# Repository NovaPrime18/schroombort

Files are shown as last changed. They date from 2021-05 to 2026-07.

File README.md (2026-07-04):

<div align="center">

# Schroombort

**An over-engineered, battery-powered mechanical soundboard.**

Press a button, hear a dumb sound. Then find out it's also a macro-pad. And a calculator.



[]()
[]()

[**▶ Watch the cinematic trailer**](https://www.youtube.com/watch?v=MM4cooladaY)

</div>

---

## Renders

<div align="center">
<table>
<tr>
<td align="center" width="50%">
Schroombort 3D render<br>
</td>
<td align="center" width="50%">
Schroombort real-life photo<br>
</td>
</tr>
</table>
</div>

---

## What is it..?

Schroombort is a battery-powered soundboard built around **36 mechanical (Cherry MX‑style) switches**, a **Vacuum Fluorescent Display**, and stereo speakers — designed to do way more than it needs to. It runs in one of three configurations, switchable depending on how you're using it.

## ⚙️ Configurations

| Mode | Description |
|---|---|
| **Soundboard** | Press a button, and a sound is played straight from the SD card. |
| **Macro-pad** | Plug it into your computer over USB‑C and assign each of the 36 buttons to a custom macro. |
| **Calculator** | Flip it into a fully functional basic calculator. |

## Specs

| Category | Detail |
|---|---|
| **Charging** | Any 5V charger, up to 2A |
| **Power management** | Fully dynamic power-path management — runs entirely on USB, entirely on battery, or a mix of both, seamlessly |
| **Inputs** | 36 configurable mechanical buttons |
| **Audio** | Stereo speakers |
| **Microcontroller** | ATxmega256A3U |
| **Display** | Vacuum Fluorescent Display (VFD) |
| **Connectivity** | USB-C |

## Repository structure

```
schroombort/
├── HardwareSchroombortFirmware/   # Firmware source code
├── PCB Files/                     # KiCad hardware design files
├── Pictures/                      # Renders & photos of the build
└── LICENSE                        # CERN-OHL-S v2.0
```

## Cinematic trailer

Because a README alone can't do it justice:

**[▶ https://www.youtube.com/watch?v=MM4cooladaY](https://www.youtube.com/watch?v=MM4cooladaY)**

## License

This project is open hardware, licensed under the **[CERN Open Hardware Licence Version 2 - Strongly Reciprocal (CERN-OHL-S v2.0)](https://ohwr.org/cern_ohl_s_v2.txt)**.

Any modified versions of the hardware distributed must remain under the same license, and source (including any modifications) must be made available.

---

<div align="center">
<sub>Built with too much love for a device whose main job is playing dumb sounds.</sub>
</div>

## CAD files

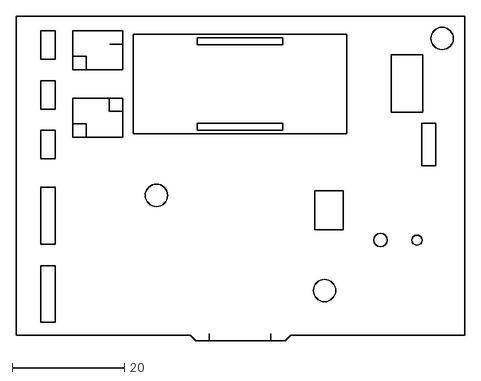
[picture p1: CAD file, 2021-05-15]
PCB Files/buttonbox2-Eco1.User.dxf
80.0 x 58.0

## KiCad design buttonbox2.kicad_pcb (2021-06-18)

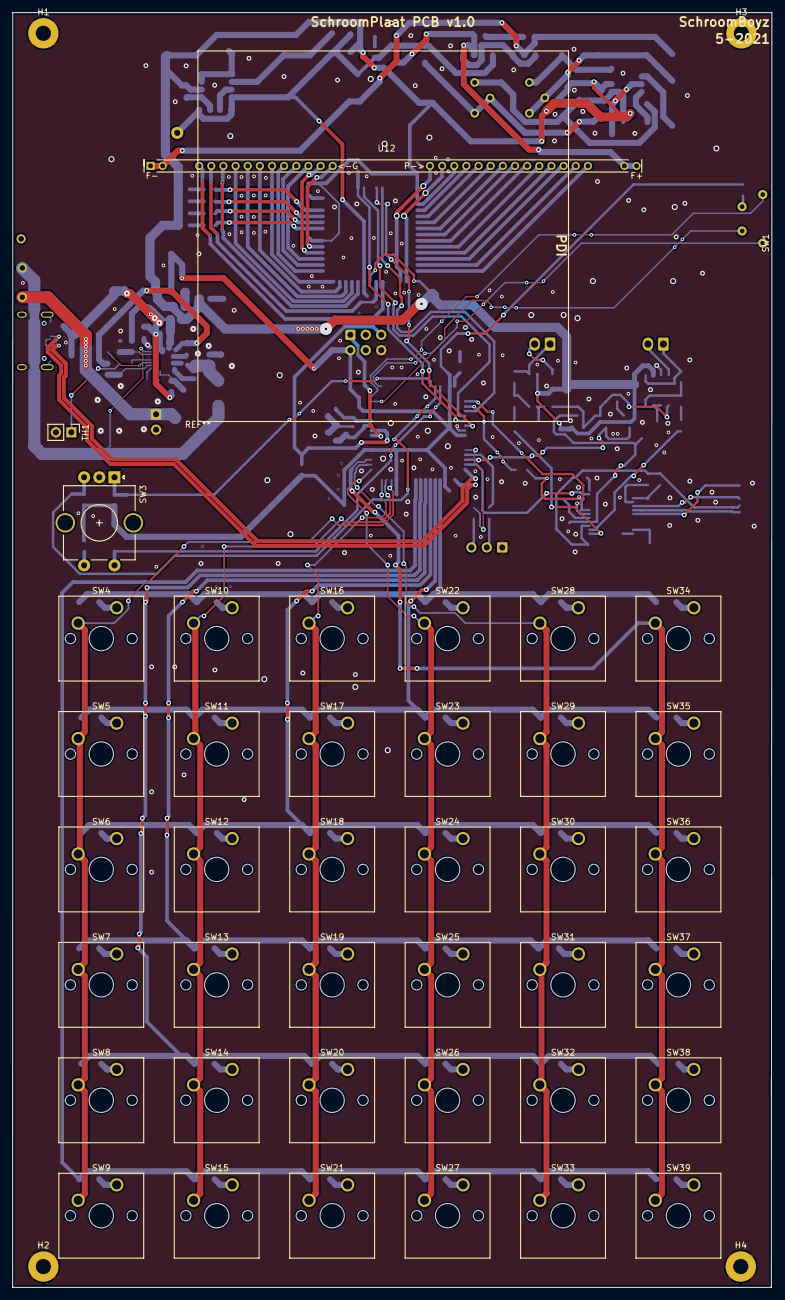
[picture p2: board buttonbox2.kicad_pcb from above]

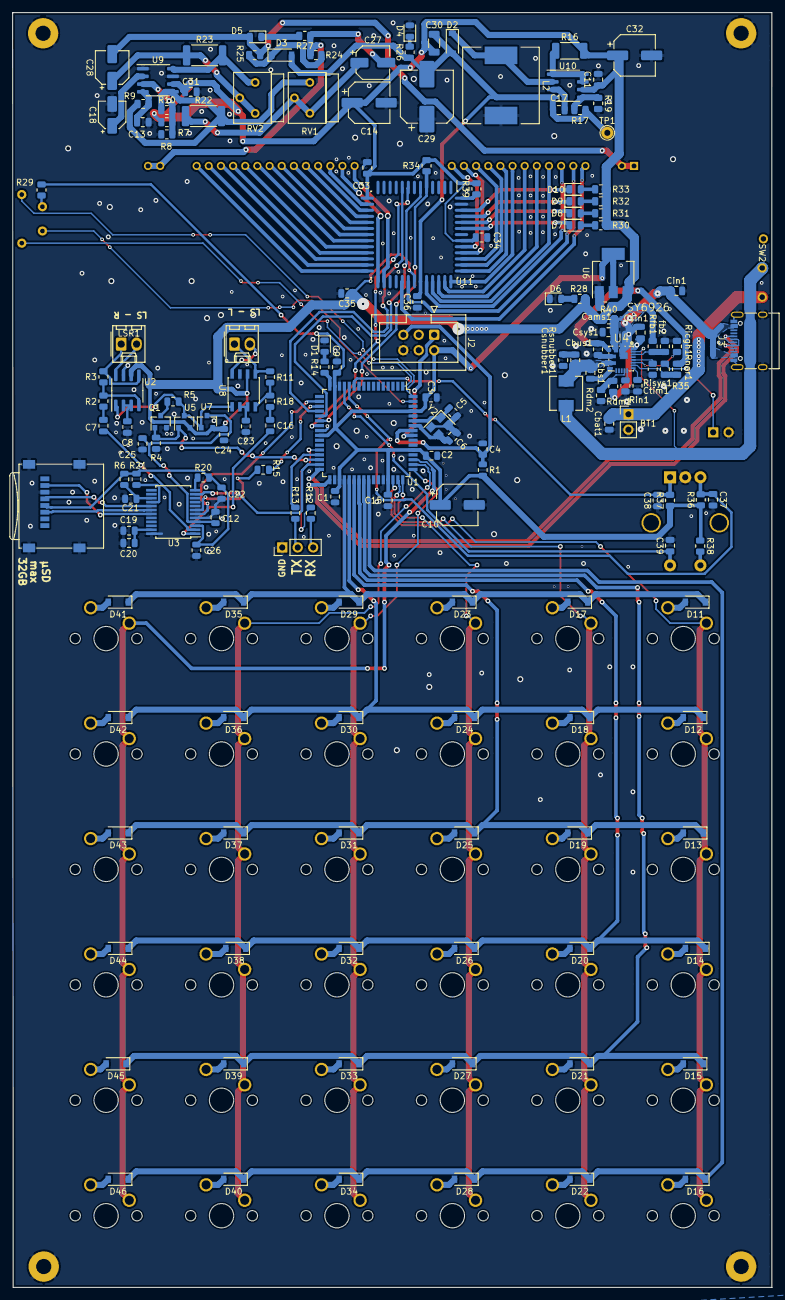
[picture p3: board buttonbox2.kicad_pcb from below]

Board: 2 copper layers, 125.0 x 209.8 mm, 213 parts (169 on the bottom side), 172 nets.

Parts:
BT1: Battery; PinHeader_1x02_P2.54mm_Vertical
C1, C2, C3, C4, C9, C11, C13, C19, C24, C25, C26, C31, C33, C34, C35, C36, C37, C38, C39: 100n; C_0805_2012Metric
C5, C6: 10p; C_0805_2012Metric
C7, C16, C20, C22: 10u; C_0805_2012Metric
C8, C12, C21, C23: 1u; C_0805_2012Metric
C10, C14, C32: 100u; CP_Elec_6.3x5.4
C15: 4.7u; C_0805_2012Metric
C17: 1n; C_0805_2012Metric
C18: 1u; CP_Elec_4x5.4
C27, C28: 10u-50V; CP_Elec_5x5.4
C29: 100u-50V; CP_Elec_8x10.5
C30: 10u 50V; C_1206_3216Metric
Cams1: C; C_0805_2012Metric
Cbat1: 20uF; C_0805_2012Metric
Cbs1: 1nF; C_0805_2012Metric
Cbus1: 20uF; C_0805_2012Metric
Cin1: 20uF; C_0805_2012Metric
Csin1: 100nF; C_0805_2012Metric
Csnubber1: DNP; C_0805_2012Metric
Csys1: 20uF; C_0805_2012Metric
Ctim1: 100nF; C_0805_2012Metric
D1, D4, D5, D6, D7, D8, D9, D10: LED; LED_0805_2012Metric
D2: 1N5819; D_SOD-123
D3: 3.6V; D_SOD-123
D11, D12, D13, D14, D15, D16, D17, D18, D19, D20, D21, D22, D23, D24, D25, D26, D27, D28, D29, D30, D31, D32, D33, D34, D35, D36, D37, D38, D39, D40, D41, D42, D43, D44, D45, D46: D_Small; D_SOD-123
H1, H2, H3, H4: MountingHole_Pad; MountingHole_2.5mm_Pad
J2: AVR-PDI-6; IDC-Header_2x03_P2.54mm_Vertical
J3: USB_C_Receptacle_USB2.0; USB_C_Receptacle_XKB_U262-16XN-4BVC11
J4: Conn_01x03_Male; PinHeader_1x03_P2.54mm_Vertical
J6: Micro_SD_Card; microSD_HC_Wuerth_693072010801
L1: 2.2uH; L_Sunlord_MWSA0518_5.4x5.2mm
L2: 470u; L_12x12mm_H8mm
LSL1: Speaker; Molex_KK-254_AE-6410-02A_1x02_P2.54mm_Vertical
LSR1: Speaker; Molex_KK-254_AE-6410-02A_1x02_P2.54mm_Vertical
Q1: 2N7002; SOT-23
R1, R2, R4, R5, R7, R8, R10, R14, R18, R27, R28, R29, R34, R36, R37, R38: 10K; R_0805_2012Metric
R3, R11: TBD; R_0805_2012Metric
R6, R20, R21: 22K; R_0805_2012Metric
R9: 2.2K; R_0805_2012Metric
R12, R13: 100R; R_0805_2012Metric
R15: 1K; R_0805_2012Metric
R16: 0.3 2W; R_2010_5025Metric
R17: 20K; R_0805_2012Metric
R19: 390K; R_0805_2012Metric
R22, R23: 150 2W; R_2512_6332Metric
R24, R25: 100; R_0805_2012Metric
R26: 100K; R_0805_2012Metric
R30, R31, R32, R33: 330; R_0805_2012Metric
R35: 4.4K; R_0805_2012Metric
R39: 56K; R_0805_2012Metric
R40: DNP; R_0805_2012Metric
RV1, RV2: 500; Potentiometer_Bourns_3339S_Horizontal
Rdm1: 33K; R_0805_2012Metric
Rdm2: 9.1K; R_0805_2012Metric
Rfb1: 33K; R_0805_2012Metric
Ricgh1: 10.666K; R_0805_2012Metric
Rin1: 1K; R_0805_2012Metric
Risys1: 36K; R_0805_2012Metric
Rnor1: 22K; R_0805_2012Metric
Rsnubber1: DNP; R_0805_2012Metric
SW1: SW_SP3T; schakelaar
SW2: SW_SPDT; SWINTCHFORBATTERY
SW3: Rotary_Encoder_Switch; RotaryEncoder_Alps_EC11E-Switch_Vertical_H20mm_CircularMoun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
SW4, SW5, SW6, SW7, SW8, SW9, SW10, SW11, SW12, SW13, SW14, SW15, SW16, SW17, SW18, SW19, SW20, SW21, SW22, SW23, SW24, SW25, SW26, SW27, SW28, SW29, SW30, SW31, SW32, SW33, SW34, SW35, SW36, SW37, SW38, SW39: SW_Push; SW_Cherry_MX_1.00u_PCB_BETTER
TH1: Thermistor_NTC; PinHeader_1x02_P2.54mm_Vertical
TP1: TestPoint; TestPoint_THTPad_D2.0mm_Drill1.0mm
U1: ATxmega256A3-AU; TQFP-64_14x14mm_P0.8mm
U2, U8, U9: LM4871; SOIC-8_3.9x4.9mm_P1.27mm
U3: YX5200-24SS; SSOP-24_5.3x8.2mm_P0.65mm
U4: SY6926; QFN-20_L4.0-W4.0-P0.45-BL
U5, U7: DMG3415; SOT-23
U6: AMS1117-3.3; SOT-223-3_TabPin2
U10: MC34063AD; SOIC-8_3.9x4.9mm_P1.27mm
U11: PT6311; LQFP-52_14x14_Pitch1mm
U12: VFD_HNV-12SS62; VFD_12SGMT
Y2: Crystal_GND24; Crystal_SMD_3225-4Pin_3.2x2.5mm
fb2: 10.3K; R_0805_2012Metric

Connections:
+3V3: C1.1, C2.1, C3.1, C9.1, C10.1, C15.1, J2.2, R1.1, R29.1, R36.1, R37.1, R38.1, U1.15, U1.25, U1.35, U1.45, U1.53, U1.61, U6.2
+5P: C12.1, C25.1, U3.4, U7.3
/MP3_player/3V3OUT: C22.1, C26.1, J6.4, R6.1, R20.2, R21.1, U3.3
/MP3_player/AMP_SHDN: R5.1, U2.1, U5.3, U7.1, U8.1
/MP3_player/DACL: C16.2, U3.1
/MP3_player/DACR: C7.2, U3.2
/MP3_player/SD_CLK: J6.5, U3.17
/MP3_player/SD_CMD: J6.3, U3.18
/MP3_player/SD_DAT: J6.7, U3.19
/MP3_player/VCOM: C19.1, C20.1, U3.23
BAT: L1.2, SW2.2, U4.19
BST: Cbs1.1, U4.7
BUS: Cbus1.1, Rnor1.1, U4.4
BUSY: U1.31, U3.11
CLK: U1.23, U11.8
Column1: SW4.2, SW5.2, SW6.2, SW7.2, SW8.2, SW9.2, U1.46
Column2: SW10.2, SW11.2, SW12.2, SW13.2, SW14.2, SW15.2, U1.47
Column3: SW16.2, SW17.2, SW18.2, SW19.2, SW20.2, SW21.2, U1.48
Column4: SW22.2, SW23.2, SW24.2, SW25.2, SW26.2, SW27.2, U1.49
Column5: SW28.2, SW29.2, SW30.2, SW31.2, SW32.2, SW33.2, U1.50
Column6: SW34.2, SW35.2, SW36.2, SW37.2, SW38.2, SW39.2, U1.51
D+: J3.A6, J3.B6, U1.33
D-: J3.A7, J3.B7, U1.32
DIN: U1.21, U11.6
DOUT: R34.2, U1.22, U11.5
FIL+: C27.2, R24.1, R27.1, U12.40, U12.41
FIL-: C28.2, D5.2, R25.2, U12.1, U12.2
HW_RX: R12.1, U1.28
HW_TX: R13.1, U1.29
LX: Cbs1.2, L1.1, Rsnubber1.2, U4.6
unnamed: BT1.1, Cbat1.1, SW2.3
unnamed: C5.2, U1.59, Y2.1
unnamed: C6.1, U1.58, Y2.3
unnamed: C7.1, R2.2
unnamed: C8.1, U2.2, U2.3
unnamed: C13.1, R9.2, U9.4
unnamed: C16.1, R18.2
unnamed: C17.1, U10.3
unnamed: C18.1, U9.2
unnamed: C21.1, R6.2, U3.15
unnamed: C23.1, U8.2, U8.3
unnamed: C27.1, R22.1, RV1.2, RV1.3
unnamed: C28.1, R23.1, RV2.2, RV2.3
unnamed: C37.1, R36.2, SW3.B, U1.12
unnamed: C38.2, R37.2, SW3.A, U1.11
unnamed: C39.1, SW3.S2, U1.13
unnamed: Csnubber1.1, Rsnubber1.1
unnamed: Csys1.1, R40.2, Rfb1.2, U4.3
unnamed: Ctim1.1, U4.13
unnamed: D1.2, R14.2
unnamed: D2.1, L2.1, U10.2
unnamed: D3.1, R24.2, R25.1
unnamed: D4.1, R26.2
unnamed: D5.1, R27.2
unnamed: D6.2, R28.2
unnamed: D7.1, U11.47
unnamed: D7.2, R30.2
unnamed: D8.1, U11.48
unnamed: D8.2, R31.2
unnamed: D9.1, U11.49
unnamed: D9.2, R32.2
unnamed: D10.1, U11.50
unnamed: D10.2, R33.2
unnamed: D11.2, SW4.1
unnamed: D12.2, SW5.1
unnamed: D13.2, SW6.1
unnamed: D14.2, SW7.1
unnamed: D15.2, SW8.1
unnamed: D16.2, SW9.1
unnamed: D17.2, SW10.1
unnamed: D18.2, SW11.1
unnamed: D19.2, SW12.1
unnamed: D20.2, SW13.1
unnamed: D21.2, SW14.1
unnamed: D22.2, SW15.1
unnamed: D23.2, SW16.1
unnamed: D24.2, SW17.1
unnamed: D25.2, SW18.1
unnamed: D26.2, SW19.1
unnamed: D27.2, SW20.1
unnamed: D28.2, SW21.1
unnamed: D29.2, SW22.1
unnamed: D30.2, SW23.1
unnamed: D31.2, SW24.1
unnamed: D32.2, SW25.1
unnamed: D33.2, SW26.1
unnamed: D34.2, SW27.1
unnamed: D35.2, SW28.1
unnamed: D36.2, SW29.1
unnamed: D37.2, SW30.1
unnamed: D38.2, SW31.1
unnamed: D39.2, SW32.1
unnamed: D40.2, SW33.1
unnamed: D41.2, SW34.1
unnamed: D42.2, SW35.1
unnamed: D43.2, SW36.1
unnamed: D44.2, SW37.1
unnamed: D45.2, SW38.1
unnamed: D46.2, SW39.1
unnamed: J2.1, U1.56
unnamed: J4.2, R13.2
unnamed: J4.3, R12.2
unnamed: LSL1.1, R11.1, U8.5
unnamed: LSL1.2, U8.8
unnamed: LSR1.1, R3.1, U2.5
unnamed: LSR1.2, U2.8
unnamed: Q1.3, R5.2
unnamed: R2.1, R3.2, U2.4
unnamed: R9.1, R10.1, R22.2, RV1.1, U9.5
unnamed: R7.2, R8.1, R10.2, U9.3
unnamed: R11.2, R18.1, U8.4
unnamed: R15.1, U3.7
unnamed: R16.1, U10.1, U10.7, U10.8
unnamed: R17.1, R19.1, U10.5
unnamed: R20.1, U3.12
unnamed: R21.2, U3.16
unnamed: R23.2, RV2.1, U9.8
unnamed: R29.2, SW1.3
unnamed: R35.1, Rnor1.2, U4.14
unnamed: R35.2, TH1.1
unnamed: R38.2, SW3.S1
unnamed: R39.2, U11.52
unnamed: Rdm1.1, Rdm2.1, U4.11
unnamed: Rfb1.1, U4.18, fb2.2
unnamed: Ricgh1.1, U4.15
unnamed: Rin1.1, U4.12
unnamed: Risys1.2, U4.16
unnamed: SW1.1, U1.1
unnamed: SW1.2, U1.64
unnamed: SW1.4, U1.63
unnamed: U11.15, U12.26
unnamed: U11.16, U12.27
unnamed: U11.17, U12.28
unnamed: U11.18, U12.29
unnamed: U11.19, U12.30
unnamed: U11.20, U12.31
unnamed: U11.21, U12.32
unnamed: U11.22, U12.33
unnamed: U11.23, U12.34
unnamed: U11.24, U12.35
unnamed: U11.25, U12.36
unnamed: U11.26, U12.37
unnamed: U11.27, U12.25
unnamed: U11.28, U12.24
unnamed: U11.31, U12.5
unnamed: U11.32, U12.6
unnamed: U11.35, U12.7
unnamed: U11.36, U12.8
unnamed: U11.37, U12.9
unnamed: U11.38, U12.10
unnamed: U11.39, U12.11
unnamed: U11.40, U12.12
unnamed: U11.41, U12.13
unnamed: U11.42, U12.14
unnamed: U11.43, U12.15
unnamed: U11.44, U12.16
PGNDBAT: BT1.2, C1.2, C2.2, C3.2, C4.2, C5.1, C6.2, C8.2, C9.2, C10.2, C11.2, C12.2, C13.2, C14.2, C15.2, C18.2, C19.2, C20.2, C21.2, C22.2, C23.2, C24.2, C25.2, C26.2, C29.1, C31.2, C32.2, C33.2, C34.2, C35.2, C36.1, C37.2, C38.1, C39.2, Cams1.2, Cbat1.2, Cbus1.2, Cin1.2, Csin1.2, Csnubber1.2, Csys1.2, Ctim1.2, D1.1, D4.2, D6.1, H1.1, H2.1, H3.1, H4.1, J2.6, J3.A1, J3.A12, J3.B1, J3.B12, J3.S1, J4.1, J6.6, J6.9, L2.2, Q1.2, R4.2, R8.2, R19.2, Rdm2.2, Ricgh1.2, Rin1.2, Risys1.1, SW3.C, TH1.2, U1.14, U1.24, U1.34, U1.44, U1.52, U1.60, U2.7, U3.5, U3.24, U4.5, U4.20, U6.1, U8.7, U9.1, U9.7, U11.51, Y2.2, Y2.4, fb2.1
PLAYER_ON: Q1.1, R4.1, U1.30, U5.1
RESET: C4.1, J2.5, R1.2, U1.57
RX: U1.18, U3.6
Row1: D11.1, D17.1, D23.1, D29.1, D35.1, D41.1, U1.36
Row2: D12.1, D18.1, D24.1, D30.1, D36.1, D42.1, U1.37
Row3: D13.1, D19.1, D25.1, D31.1, D37.1, D43.1, U1.38
Row4: D14.1, D20.1, D26.1, D32.1, D38.1, D44.1, U1.39
Row5: D15.1, D21.1, D27.1, D33.1, D39.1, D45.1, U1.40
Row6: D16.1, D22.1, D28.1, D34.1, D40.1, D46.1, U1.41
SIN: Cin1.1, Csin1.1, J3.A4, J3.A9, J3.B4, J3.B9, Rdm1.2, U4.1, U4.2
STATLED: R14.1, U1.16
STB: U1.20, U11.9
SYS: C11.1, C14.1, C24.1, C30.1, C31.1, C32.1, C33.1, C34.1, C35.1, Cams1.1, R7.1, R16.2, R28.1, R30.1, R31.1, R32.1, R33.1, R34.1, R39.1, R40.1, U2.6, U5.2, U6.3, U7.2, U8.6, U9.6, U10.6, U11.14, U11.33, U11.45
TX: R15.2, U1.19
VEE: C17.2, C29.2, C30.2, C36.2, D2.2, D3.2, R17.2, R26.1, TP1.1, U10.4, U11.34

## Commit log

2021-05-15 Added hardware battery disconnect
    [Battery.sch, buttonbox2.sch]
2021-05-15 Ja crap toch weer aan de PCB gezeten
    [Battery.sch, buttonbox2.kicad_pcb, buttonbox2.sch]
2021-05-17 Changed oscillator capacitor values from 22pF to 10pF
    [buttonbox2.sch]
2021-05-18 Added SY6926 component values and some minor cleanup
    [Battery.sch, buttonbox2.kicad_pcb, buttonbox2.sch]
2021-05-18 Slight footprint shuffle for the VFD
    [MP3_player.sch, buttonbox2.kicad_pcb]
2021-05-18 alles op B.cu ivm assemblage
    [buttonbox2.kicad_pcb]
2021-05-18 Added footprint of U9
    [buttonbox2.kicad_pcb]
2021-05-18 shuffled things around
    [Power.sch, buttonbox2.kicad_pcb, main.sch]
2021-05-24 NTC circuit and values added
    [Battery.sch, Power.sch, main.sch]
2021-06-03 Added a rotary encoder and almost all BC values
    [Battery.sch, buttonbox2.kicad_pcb, buttonbox2.sch]
2021-06-11 Final schematic edits, PCB layout
    [Battery.sch, ButtonMatrix.sch, MP3_player.sch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]
2021-06-11 pretty much routed everything
    [Battery.sch, buttonbox2.kicad_pcb, buttonbox2.sch]
2021-06-18 Fixed some DRC errors and some incorrect wiring
    [Battery.sch, MP3_player.sch, buttonbox2.kicad_pcb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]
2021-06-18 Added SYS disconnect, routed USB, changed few things
    [Battery.sch, buttonbox2.kicad_pcb, buttonbox2.sch]
2021-06-19 Shrank the PCB size, rerouted stuff, added a lot of silkscreen art.
2021-06-20 Changed a lot, ordered the final thing
    [Battery.sch, MP3_player.sch, buttonbox2.sch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]
2021-07-01 Added SchroombortFirmware folder
    [buttonbox2.sch]
2026-07-04 Tidied up
    [Battery.sch, ButtonMatrix.sch, MP3_player.sch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]
